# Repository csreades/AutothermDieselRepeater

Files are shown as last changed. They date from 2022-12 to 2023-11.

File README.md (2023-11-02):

# AutothermDieselRepeater
A set of scripts to integrate autotherm diesel heater into home assistant through MQTT.

This results in a live and updated controller for HA that is able change all settings available through the (PU-27) controller. The controller polls for settings so changes on HA will reflect in the controller and vice versa allowing for a seamless integration.

Example lovelace card is included which results in:

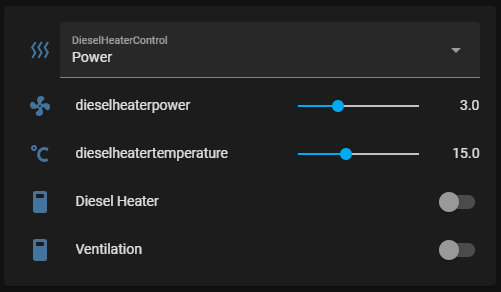
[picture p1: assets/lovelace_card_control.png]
lovelace card


The card requires three helpers to be created to work correctly. Screenshots of these are in the HA folder.

The integration has three elements:

	Control Panel
	     |
	Arduino Mega    -   Raspberry Pi   -   MQTT     - HA
        |
	   Heater

 - Arduino Mega 2560
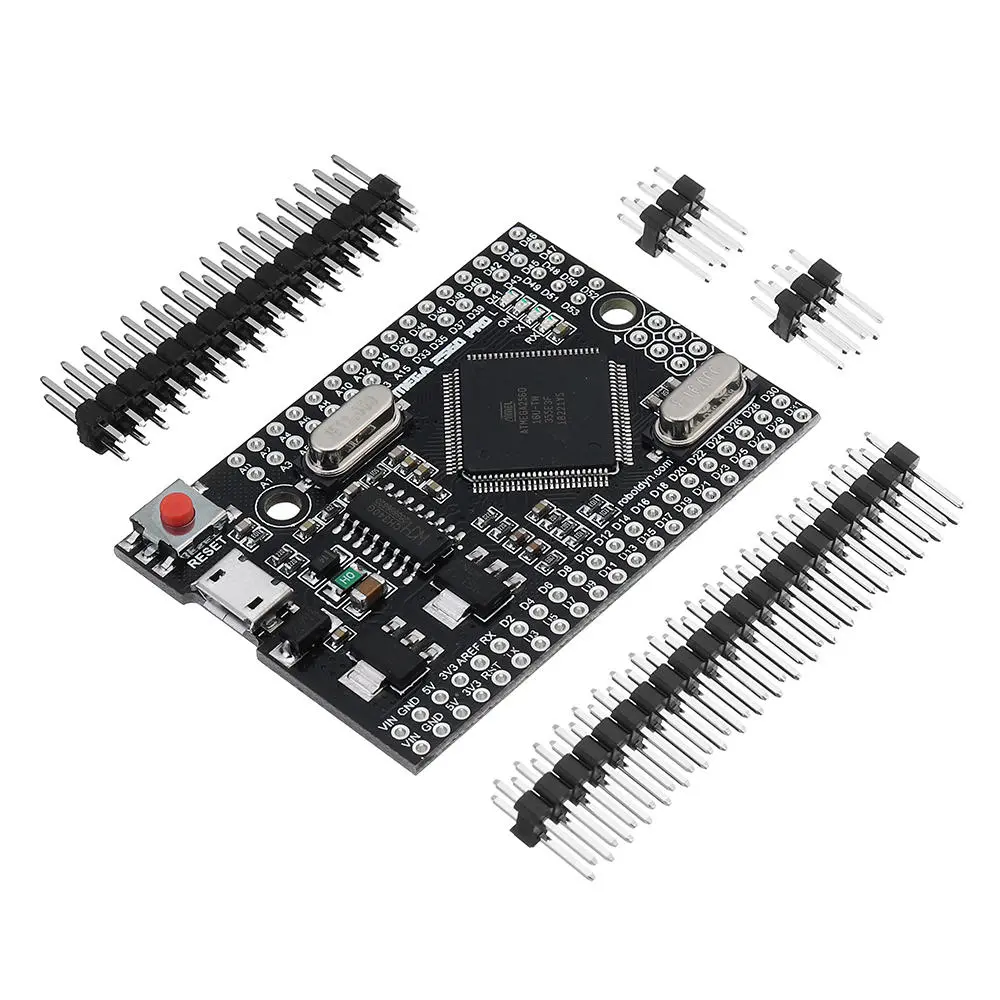
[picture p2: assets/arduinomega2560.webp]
Arduino2560

 - Raspberry Pi (acting as a wifi-mqtt bridge)
 - MQTT and HA server
 
The arduino sketch is included in "ArduinoMega", the arduino Mega was selected as it has three hardware serial ports and runs on 5V logic. It is placed inbetween the heater and the control panel so that it can listen and repeat all traffic to the Pi but also inject commands. The sketch only has the shutdown command inbuilt and the rest of the commands are created by the Pi. Currently there seems to be a bug in this code that inserts extra "FFFF"s in the traffic.
 
The python file running on the Pi is in "RaspberryPi". It translates the repeated data to variables and posts them to MQTT. It also subscribes to certain control and if there is a published change it creates the command and sends it to the arduino for insertion.
 
The final scripts are in "HomeAssistant" and are excerpts from my HA in how I have integrated this specific system.
 
Finally there are the STL files for a mount for the mega so it can be mounted.
 
For wiring:

	Controller
		Red		- Heater-Red
		Blue		- Arduino GND
		Green (RX)	- Arduino 18 (TX)
		White (TX)	- Arduino 19 (RX)

	Heater
		Red		- Heater-Red
		Blue		- Arduino GND
		Green (TX)	- Arduino 17 (RX)
		White (RX)	- Arduino 16 (TX)

Credit for help in integration comes from:

https://grimoire314.wordpress.com/2018/08/22/planar-diesel-heater-controller-reverse-engineering/
https://grimoire314.wordpress.com/2019/03/21/autoterm-planar-diesel-heater-controller-reverse-engineering-part-2/
http://schlussdienst.net/html/planar-2d-protocol.md

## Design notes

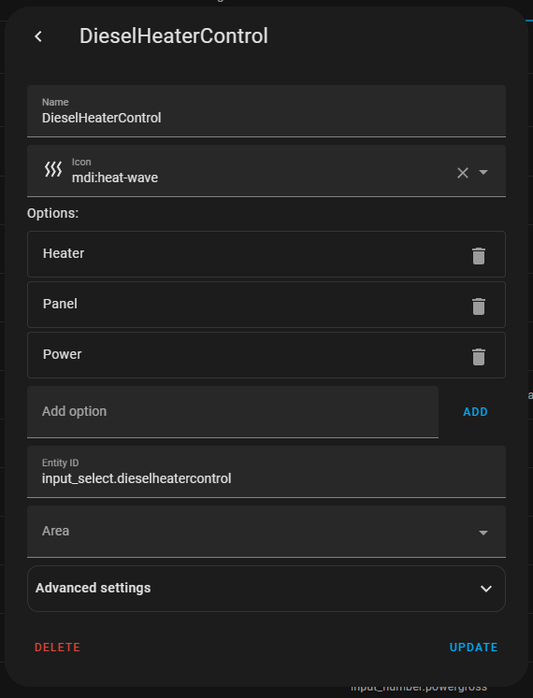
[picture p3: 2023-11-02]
HomeAssistant/DHC_helper.png

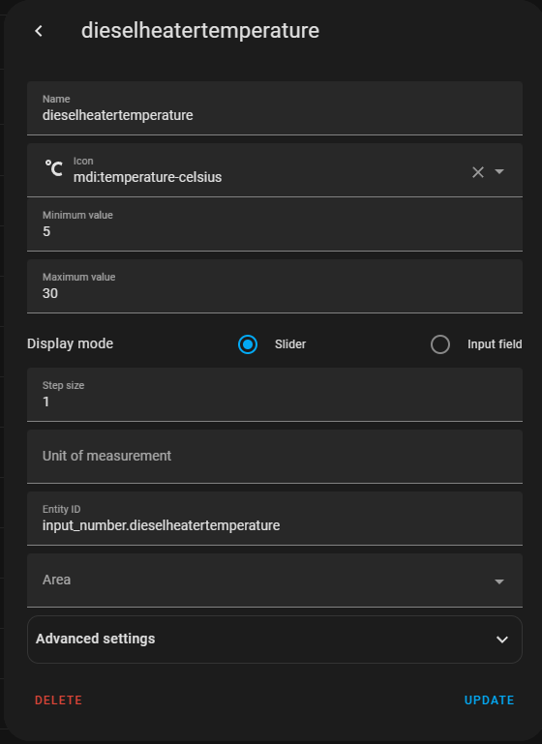
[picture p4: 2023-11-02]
HomeAssistant/DHT_helper.png

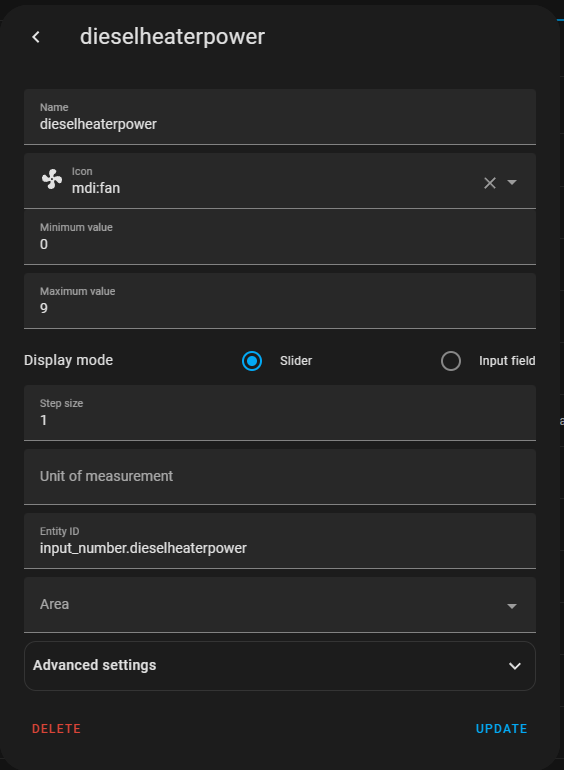
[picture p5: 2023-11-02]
HomeAssistant/DHP_helper.png

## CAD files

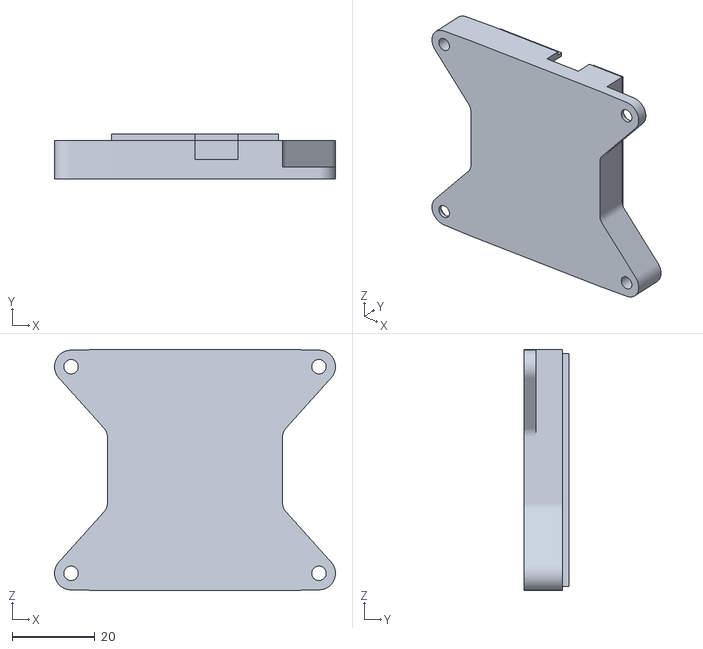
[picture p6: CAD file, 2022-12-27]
STL Files/base.stl
68.0 x 11.0 x 58.4

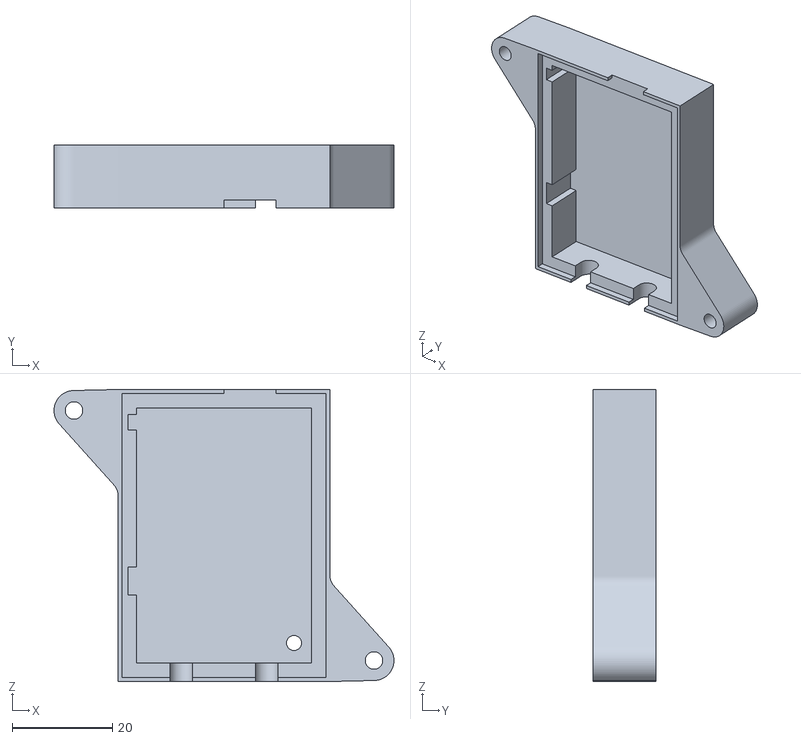
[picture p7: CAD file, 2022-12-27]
STL Files/lid.stl
68.0 x 12.6 x 58.4

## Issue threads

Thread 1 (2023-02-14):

Need Info: Possble to use the script with Comfort Control Panel

Flori261, 2023-02-14:
Hey thank for the Work! Do you know if its posstible to use the Script with the Comfort Control Panel?

Thanks in advance!

csreades, 2023-02-16:
I cannot say for certain as I do not have one but I would say it will. The
controller only sends some basic commands really and the heater does the
work. Therefore unless you have to “upgrade” the heater the controllers
should all work the same.

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

Closed 2023-10-03.

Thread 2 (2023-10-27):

Trying myself on this project

EICHKORN-media, 2023-10-27:
Hi and first of all thanks for providing your code!
This is pretty much my first project of this kind and I'm not sure how succsessfull I'll be on implementing it into my Smart Van system since I'm also not big of a coder but I'm very keen and curious! :)
So there might come some more questions in the near future but I'd like to start with two simple ones if you don't mind?

1. In your wiring setup on the heater side you state that the red wire should go to Heater Red. I assume you mean Controller-Red, right?
2. I'm already using some ESP32 in my van and would really like to use one for this purpose as well. It also comes with four serial ports (2x TX & 2x RX) and it has a 3.3V and a 5V pin. Not sure about the internal voltage logic, tho. Do you think it would work with an ESP32 or is there anything I'd have to keep in mind or change my setup so it would?

Thanks for your help!
Jens

csreades, 2023-10-28:
Great to hear and I hope it goes well.

1. The red goes to red, this is 12 v and the devices we add don’t need/use
this wire.
2. Potentially it works, the RX and TX pins need to be 5v tolerant to not
damage the ESP. And if they are outputting only 3.3v there’s no guarantee
that the devices will see the signals. To ensure it works you could get a
logic level shifter to ensure it works.

Craig

On Sat, 28 Oct 2023 at 00:12, Jens M Eichkorn ***@***.***>
wrote:

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

Tidle999, 2023-10-28:
Hello,

I would like to join in here as I've been following the project for a while and finally want to implement it in my camper. I have the same basic requirements as smartventure, so I don't have as many coding skills.
Currently, I have a Raspberry Pi 3 B running Home Assistant with Hass.io. to save energy I don't want to use another Raspberry Pi. I've noticed that Hass.io offers the option to run Python scripts as integrations, which can then be exposed as services in Hass.io. Would this work, or are there any specific things to consider or adjust? Thank you for your assistance.

csreades, 2023-10-28:
My solution was based on what I had available in my van already. I already
have a Pi doing some other things and it made sense to include it.

If you haven’t got a Pi in the van already I think it should be based on
what connectivity you want.

If just Bluetooth/ WiFi an ESP would be fine. If no/serial connectivity
then a mega like I used.

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

smartVanture, 2023-10-30:
Thanks for your reply!
I have now bought the same Mega myself, as this will allow me to rule out possible sources of error regarding the conroller.

Now that I wanted to connect as stated by you, I had to find out, that the colours of the wires connected to my controller are different. I've got: red, white, black and yellow. Any idea which might be which? Or where to find an corresponding wiring diagram? Red is probably still 12V but the rest? 🤷🏽‍♂️

csreades, 2023-10-30:
It should be fairly easy to identify +ve and ground with a multi-meter? Once you have done that then you can guess at RX/TX, and if it doesn't work just reverse them?

smartVanture, 2023-10-30:
That's true! Will try that probably on Wednesday. Cheers!

smartVanture, 2023-11-02:
Little Update from my side: Working great so far! I could implement everything exept those three entities:

  - entity: input_select.dieselheatercontrol
  - entity: input_number.dieselheaterpower
  - entity: input_number.dieselheatertemperature

 I can't find where they should come from. They are also not defined in the configuration.yaml and I get the errors 'entity not available' for those three entities if I'm trying to create the example lovelace card. Any idea what the problem might be?

 Because of that error, I'm currentyl only able to start heater and fan but can't set any temperature or fan speed.

csreades, 2023-11-02:
I believe the issue is that these three items work on helpers that are required in HA. I have added screen shots for each helper, they are created through the UI.

smartVanture, 2023-11-02:
Ohh I see, thanks!
What are the DieselHeaterControll Options connected to, tho?

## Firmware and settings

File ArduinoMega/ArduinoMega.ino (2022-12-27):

bool repeat = true;

#define RaspberrySerial Serial
#define ControllerSerial Serial1
#define HeaterSerial Serial2

//Baud rate for autotherm heater
#define baudRate 9600
//delay in ms
#define serial_timeout 20

//Light toggling variables
#define freq 500
bool lightOn = false;
long loopTimer = 0;

void setup() {
  HeaterSerial.begin(baudRate);
  ControllerSerial.begin(baudRate);
  RaspberrySerial.begin(115200);
  pinMode(LED_BUILTIN, OUTPUT);
}
void loop() {
  digitalWrite(LED_BUILTIN, lightOn);
  if (millis() > (loopTimer + freq)) {
    loopTimer = millis();
    lightOn = !lightOn;
  }

  if ((HeaterSerial.available() > 0) || (ControllerSerial.available() > 0) || (RaspberrySerial.available() > 0)) {
    runSerial();
  }
}


void runSerial() {
  //RaspberrySerial.println("Data in.");
  if (repeat) {
    //we are in just repeat mode
    if (HeaterSerial.available() > 0) {
      delay(serial_timeout);
      RaspberrySerial.print("H >> ");
      while (HeaterSerial.available() > 0) {
        char inByte = HeaterSerial.read();
        ControllerSerial.write(inByte);
        RaspberrySerial.print("0X");
        RaspberrySerial.print(inByte, HEX);
        RaspberrySerial.print(" ");
      }
      RaspberrySerial.println("");
    }
    if (ControllerSerial.available() > 0) {
      delay(serial_timeout);
      RaspberrySerial.print("C >> ");
      while (ControllerSerial.available() > 0) {
        char inByte = ControllerSerial.read();
        HeaterSerial.write(inByte);
        RaspberrySerial.print("0X");
        RaspberrySerial.print(inByte, HEX);
        RaspberrySerial.print(" ");
      }
      RaspberrySerial.println("");
    }
  } else {
  }

  if (RaspberrySerial.available() > 0) {
    char inByte = RaspberrySerial.read();
    if (inByte == 'R') {
      repeat = true;
    }
    if (inByte == 'S') {
      repeat = false;
    }

    if(inByte =='F'){
      RaspberrySerial.println("Shuting down.");
      HeaterSerial.write(0xAA);
      HeaterSerial.write(0x03);
      HeaterSerial.write(0x00);
      HeaterSerial.write(0x00);
      HeaterSerial.write(0x03);
      HeaterSerial.write(0x5d);
      HeaterSerial.write(0x7c);
    }

    if(inByte =='r'){
      RaspberrySerial.println("Sending raw.");
      delay(5);
      while(RaspberrySerial.available()>0){
        HeaterSerial.write(RaspberrySerial.read());
      }
    }
  }
}

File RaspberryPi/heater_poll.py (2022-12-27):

import crcmod.predefined
import serial
from time import sleep
import crcmod
import paho.mqtt.client as mqtt
from paho.mqtt.subscribeoptions import SubscribeOptions

def finishMessage(byteList):
	newPacket = bytearray()
	newPacket.append(0x72)

	for bit in byteList:
		newPacket.append(bit)

	crcfunc = crcmod.predefined.mkCrcFun('modbus')

	crc = crcfunc(byteList)

	val = bytes([crc >> 8 % 256,crc % 256])

	for bit in val:
		newPacket.append(bit)

	return newPacket


def rxMessage(client, userdata, msg):
	global heater_mode_val, heater_temp_val, ventilation_val, power_level_val
	print(f"Message received [{msg.topic}]: {msg.payload}")
	#print(client)
	#print(userdata)
	if(msg.topic == "van/diesel/control"):
		if(msg.payload == b'On'):
			print("Sending heat command")
			powerOn(heater_mode_val, heater_temp_val, ventilation_val, power_level_val)
		if(msg.payload == b'Off'):
			print("Sending off command")
			ser.write('F'.encode())

	if(msg.topic == "van/diesel/setpoint_heater_temp"):
		heater_temp_val = int(msg.payload)
		print(heater_temp_val)
		send_command(heater_mode_val, heater_temp_val, ventilation_val, power_level_val)

	if(msg.topic == "van/diesel/setpoint_power_level"):
		power_level_val = int(msg.payload)
		print(power_level_val)
		send_command(heater_mode_val, heater_temp_val, ventilation_val, power_level_val)

	if(msg.topic == "van/diesel/setpoint_heater_mode_string"):
		if(msg.payload == b'Power'):
			heater_mode_val = 4
		if(msg.payload == b'Panel'):
			heater_mode_val = 2
		if(msg.payload == b'Heater'):
			heater_mode_val = 1
				
		print(heater_mode_val)
		send_command(heater_mode_val, heater_temp_val, ventilation_val, power_level_val)

	if(msg.topic == "van/diesel/setpoint_ventilation"):
		ventilation_val = int(msg.payload)
		print(ventilation_val)
		send_command(heater_mode_val, heater_temp_val, ventilation_val, power_level_val)


def parse_and_submit(serial_data, ident_string, index, topic):
	lines = str(serial_data)
	find_index = lines.find(ident_string)
	if(find_index > -1):
		#found the string in the data
		serial_slice = lines[find_index:]
		#move the found data to a slice
		hex_data = serial_slice.split(" ")
		if(len(hex_data) > (index + 1)):
			#not teh last element so not split data
			data = hex_data[index]
			if(len(data) < 5): #0x0 0x00 0xFFFF0 0xFFFF00
				data = data[2:]
			else:
				data = data[8:]

			try:
				value = int(data, 16)
				client.publish(topic, value)
				return value
			except:
				client.publish(topic+"_debug", "parse_error" + data)



def send_command(mode, temp, vent, powe):
	packet = bytearray()
	packet.append(0xAA) #start
	packet.append(0x03) #from controller
	packet.append(0x06) #6 bytes in message
	packet.append(0x00) #blank
	packet.append(0x02) #get/set command
	packet.append(0xFF) #unused
	packet.append(0xFF) #unused
	packet.append(mode)
	packet.append(temp)
	packet.append(vent)
	packet.append(powe)

	message = finishMessage(packet)
	
	for bit in message:
		print(hex(bit))

	for i in range(2):
		ser.write(message)
		sleep(0.4)		
		ser.flushInput()

		
def powerOn(mode, temp, vent, powe):
	packet = bytearray()
	packet.append(0xAA)
	packet.append(0x03)
	packet.append(0x06)
	packet.append(0x00)
	packet.append(0x01) #turn on
	packet.append(0xFF)
	packet.append(0xFF)
	packet.append(mode)
	packet.append(temp)
	packet.append(vent)
	packet.append(powe)

	message = finishMessage(packet)
	
	for bit in message:
		print(hex(bit))

	for i in range(2):
		ser.write(message)
		sleep(0.4)		
		ser.flushInput()




mqtt_broker = ""
mqtt_port = 1
mqtt_user = ""
mqtt_pswr = ""


client = mqtt.Client("VAN-DIESEL", protocol=5)
client.username_pw_set(mqtt_user, mqtt_pswr)
client.connect(mqtt_broker, mqtt_port)

client.on_message = rxMessage


options = SubscribeOptions(qos = 1, noLocal = True)

client.subscribe("van/diesel/control")
client.subscribe("van/diesel/setpoint_power_level", options=options)
client.subscribe("van/diesel/setpoint_heater_temp", options=options)
client.subscribe("van/diesel/setpoint_ventilation", options=options)
client.subscribe("van/diesel/setpoint_heater_mode_string", options=options)

heater_temp_cont = "C >> 0XFFFFFFAA 0X3 0X1 0X0 0X11 0X" #for some reason FFFF's are added to messages? needs fixing
heater_temp_cont_idx = 7

heater_temp_heat = "H >> 0XFFFFFFAA 0X4 0X1 0X0 0X11 0X"
heater_temp_heat_idx = 7

heater_state_string = "H >> 0XFFFFFFAA 0X4 0X13 0X0 0XF"
heater_state_index  = 16

heater_voltage_string = heater_state_string
heater_voltage_index  = 13

heater_coretemp_string = heater_state_string
heater_coretemp_index  = 15

heater_fanspd_string = heater_state_string
heater_fanspd_index  = 18

heater_fanspd2_string = heater_state_string
heater_fanspd2_index  = 19

heater_fuel_string = heater_state_string
heater_fuel_index  = 21

heater_fuel2_string = heater_state_string
heater_fuel2_index  = 23

heater_glow_string = heater_state_string
heater_glow_index  = 24


setpoint_string = "H >> 0XFFFFFFAA 0X4 0X6 0X0 0X"
heater_mode  = 9
heater_temp  = 10
ventilation  = 11
power_level  = 12
unknown      = 8
unknown2      = 7

heater_mode_val = -1
heater_temp_val = -1
ventilation_val = -1
power_level_val = -1
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
